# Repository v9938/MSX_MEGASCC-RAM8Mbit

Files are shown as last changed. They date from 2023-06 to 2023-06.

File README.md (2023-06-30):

# MSX MEGA-SCC RAM 8Mbit version  

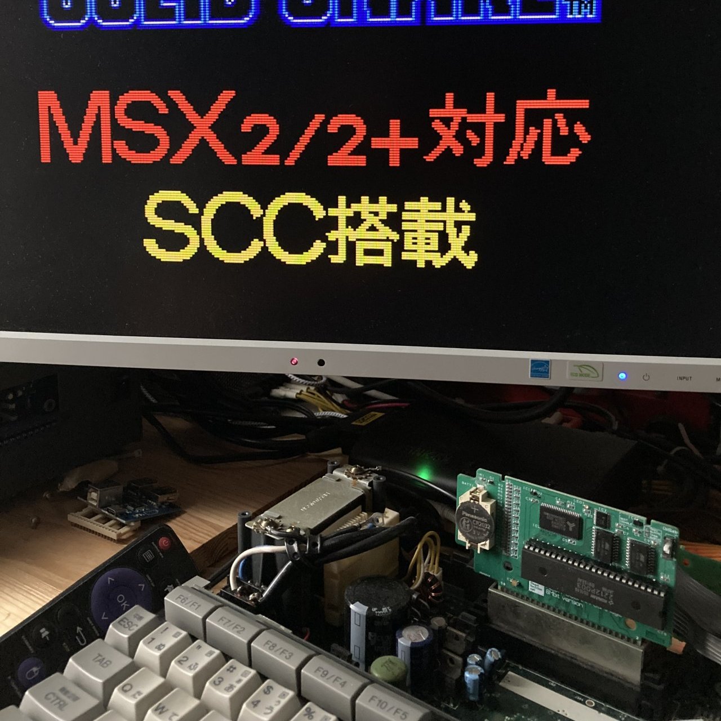
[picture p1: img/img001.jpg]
  

SCCのFlash Cartridge MEGA-SCC(似非SCC)のSRAM Versionです。  
SCC (2212P003) の最大容量は4Mbitですが、独自拡張をすることで8Mbitに対応しています。  

スイッチ切り替えにて4Mbitx2のマルチSCCカートとしても使用することができます。　　

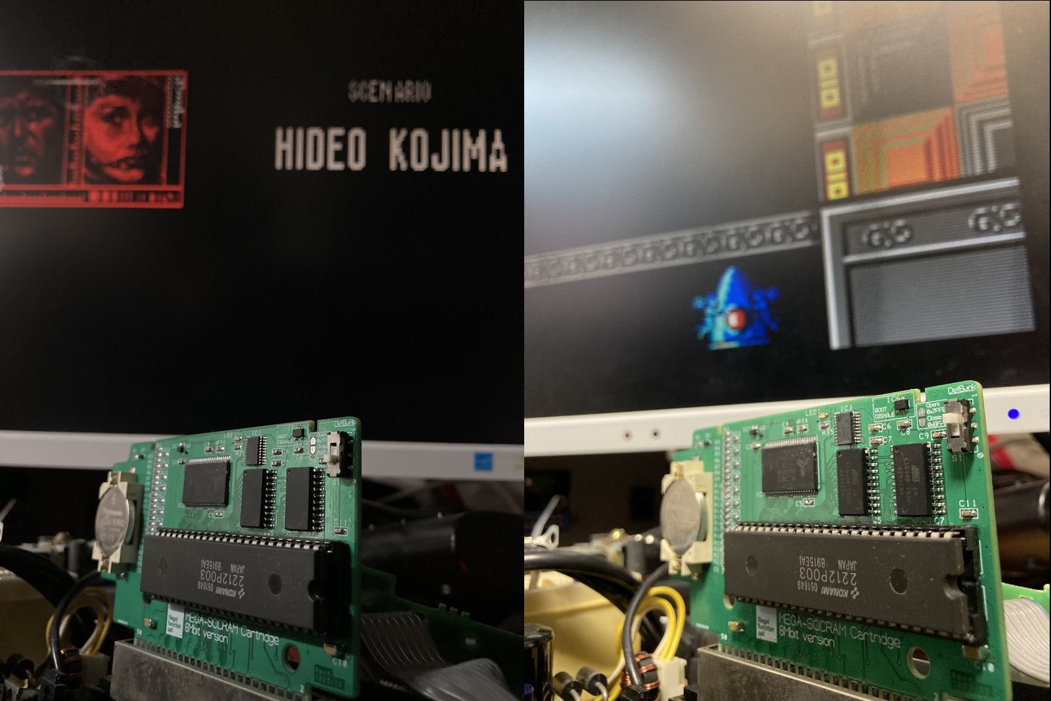
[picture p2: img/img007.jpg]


DACには、KONAMI051650と同等回路をあえて採用し、音質面で違いが出ないようにしています。   
ノイズ対策として大容量コンデンサーを搭載、SCC自体からでるノイズを低減させています。  

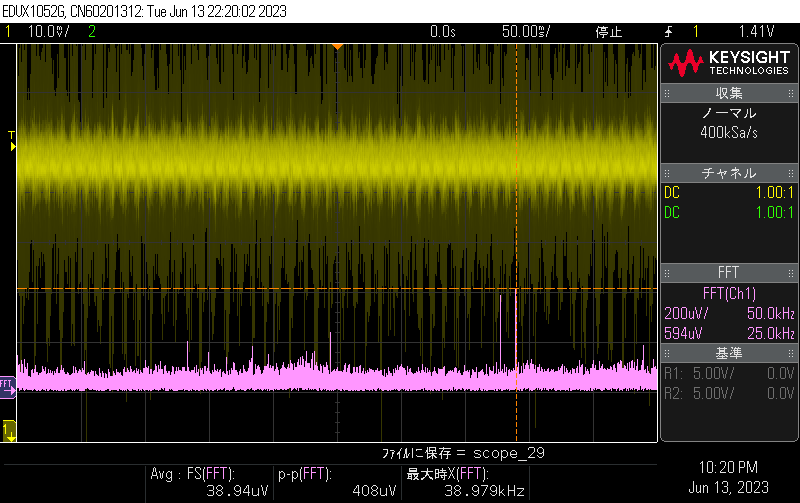
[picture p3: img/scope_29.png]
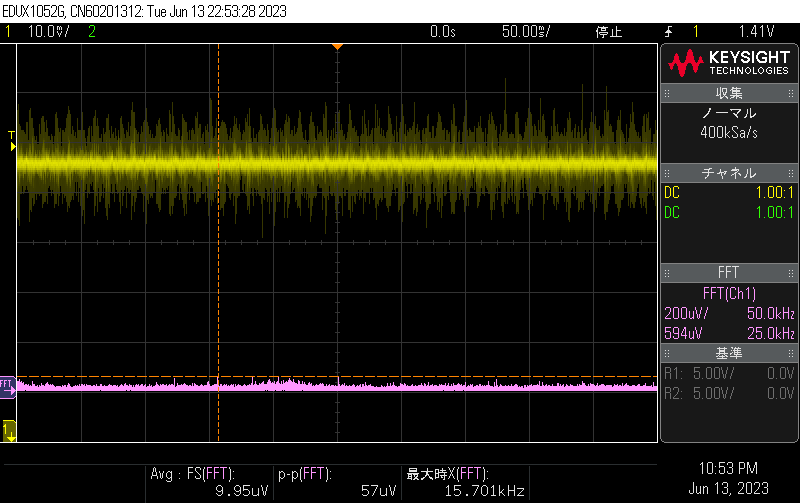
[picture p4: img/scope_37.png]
   
(左：オリジナル相当　右：本製品)

SRAMのバックアップ用には、電圧監視ICを搭載しておりデータ消失が起きにくい回路構成になっています。  

マグネットセンサーによる一時的な切り離し回路も実装しており、スマートなケース組み込みが可能です。  

## ■ 本製品の頒布について

下記ショップで取り扱っていただいています。  

家電のKENちゃん  
<https://www.kadenken.com/view/item/000000001604>  

ユーザにてSCC (2212P003) を実カートリッジから取り外しと本製品への半田付けが必要です。  
DACのKONAMI051650については取り外し不要です。基板上に等価回路を実装しています。  

カセットシェルは、KONAMIのMSX Cassette(要加工)   
またはRGR製のTransparent Cartridge Shell for MSX Konami-styleに対応しています。

## ■ 付属品
- MEGA-SCC RAM 基板(半完成品) x 1
- バックアップ電池 CR2032(パナソニック製) x 1  

## ■ 基板の説明

① 電池ボックス ... CR2032の電池ボックスです。  
② SCC取り付け場所 ... SCC (2212P003) を半田付けしてください。（ICソケットを使用するとケースに収まりません）  
③ マグネットセンサー... センサー近辺に磁石を近づけると、一時的にカセットを切り離すことができます。  
④ BANK切り替えスイッチ ... マルチSCCカートで使用時に使用するバンクを切り替えます。  
⑤ LED ... ソフト制御可能なLEDです。  

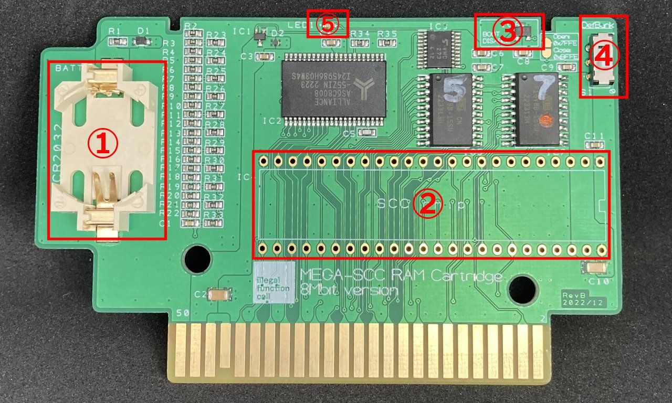
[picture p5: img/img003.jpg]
  

## ■ 基板の組み立て
本製品は、表面実装部品はすべて実装済みの半完成品での頒布になります。  

IC4に、SCC (2212P003) を半田付け、電池を取り付ければ完成です。取り付け方向に注意してください。  

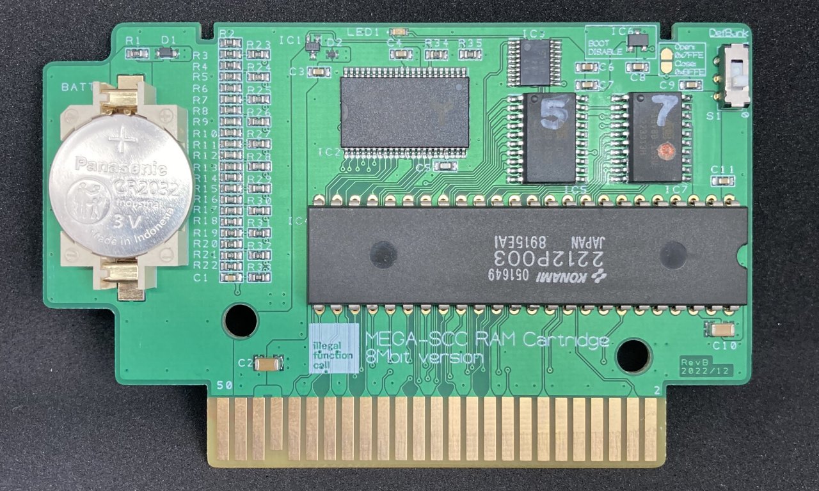
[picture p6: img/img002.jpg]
  

## ■ 電池の取り付け・交換方法
電池の＋側を上にして取り付けください。  
挿入時は、電池ケース凹部に＋側の表示側を先にはめ込んでください。  
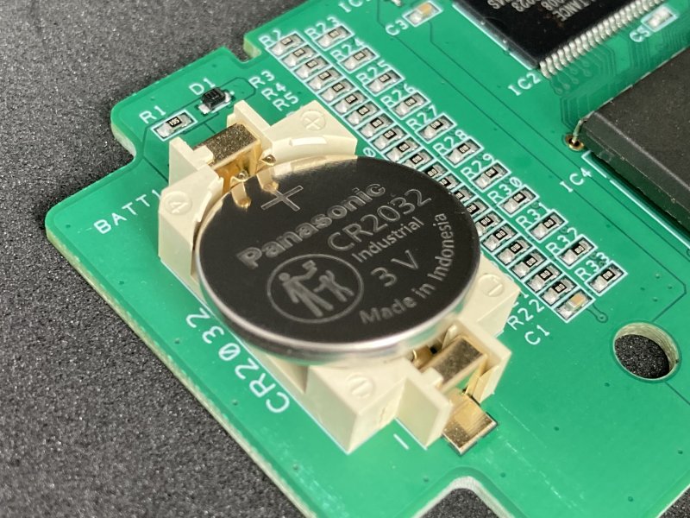
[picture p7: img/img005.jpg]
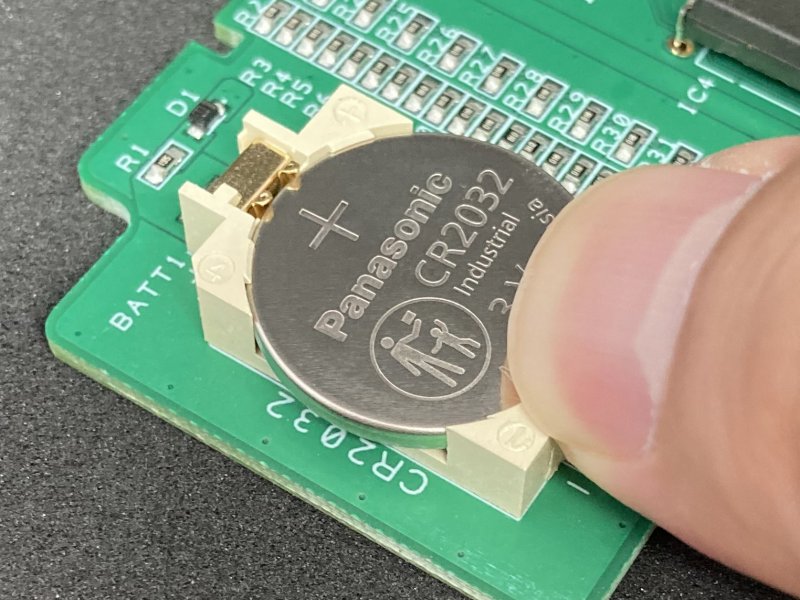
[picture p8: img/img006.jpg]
   

（許容充電電流のスペックにより）  
交換品のCR2032については、パナソニック/マクセル/SONY/村田製を推奨します。  

## ■ マグネットセンサーの使い方
センサー近辺に磁石を近づけると、一時的にカセットを切り離すことができます。  
SRAM書き換え時など、ROMから起動させたくない場合に利用してください。  
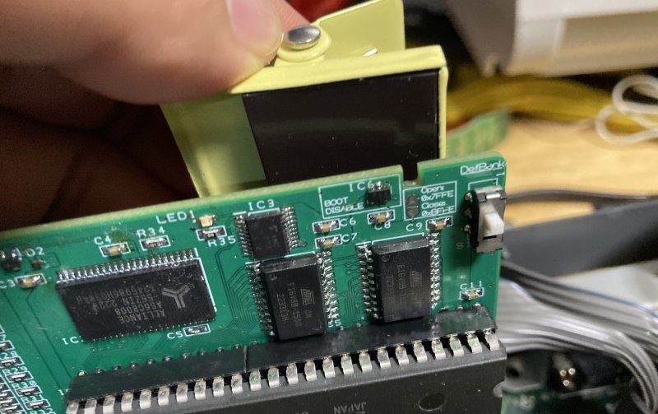
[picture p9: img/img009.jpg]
  

## ■ バンク切り替えスイッチ
スイッチの切り替えで前半と後半4MbitをSWAPすることができます。  
動作中はどちらかに固定して使用してください。  

4MbitまでのROMデータを使用する場合はマルチカートとして使用することが可能です。  
使いたいBANKにスイッチを切り替えて使用してください。  

## ■ KONAMI カセットシェルを使う場合の注意
シェルの加工が必要です。赤丸の突起を折り取ってください。  
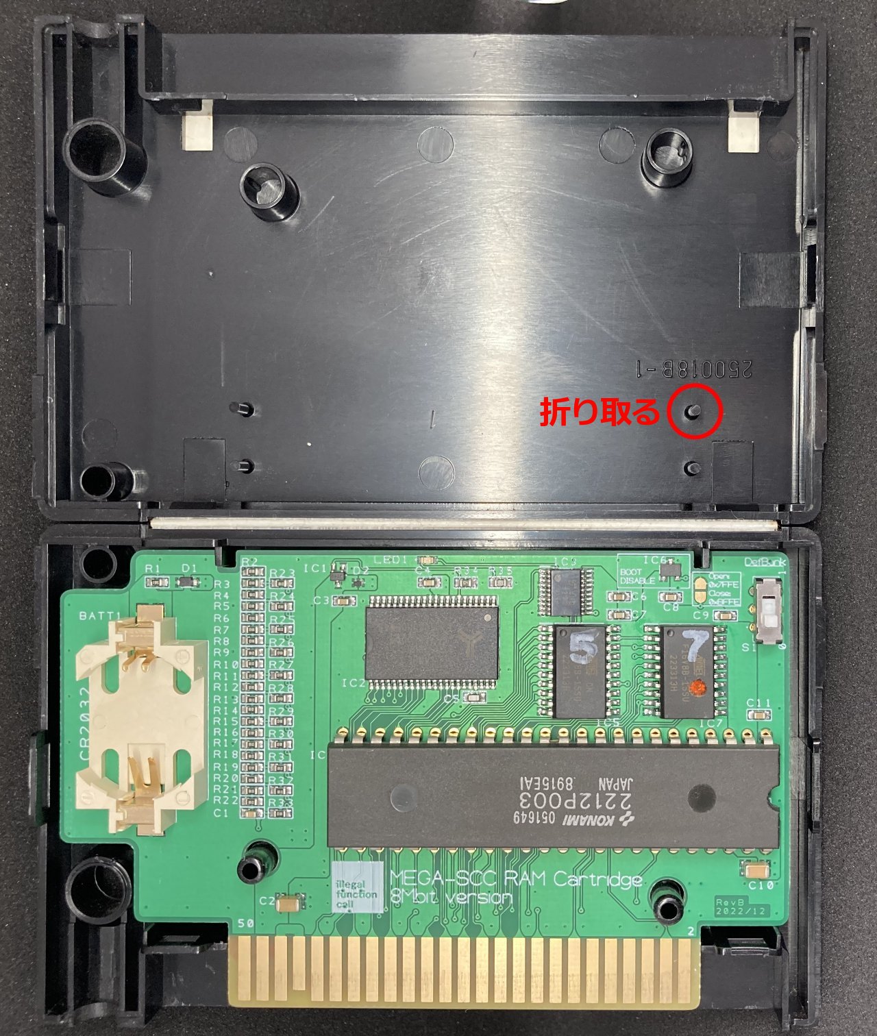
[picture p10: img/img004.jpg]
  

## ■ 動作確認ソフト
動作確認用に、SRAM領域をWrite/Read/Verifyする。SCCRAM_TESTを用意しています。
```
>sccram.com
```
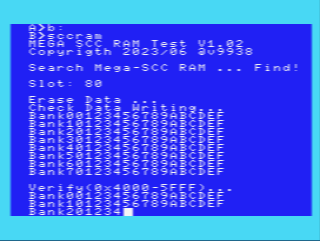
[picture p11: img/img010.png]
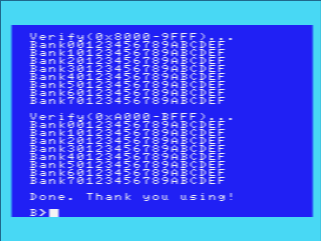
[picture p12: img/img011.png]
   

ソースコードは、z88dkでコンパイル可能です。コンパイルオプションは下記になります。  
```
>zcc +msx -create-app -subtype=msxdos -lmsxbios  main.c -o xxxx.com`  
```

## ■ その他対応ソフトについて
niga氏作成のMGLOADにて、拡張領域を含み、認識および書き込み可能なことを確認しています。  

### ●MGINST.COMについて
SCC RAM DISKの作成ができる辻川氏のMGINST.COMについては、  
似非SCC RAMと非互換部分の問題でフリーズします。  
同梱しているPatchを実行して修正してください。(似非SCC RAMより8K Byte使える容量が減ります)  

[MGINST.COM Ver2.15用Patchソフト](./MGINST_PATCH/mgpatch.com) [[zip形式]](./MGINST_PATCH/mgpatch.zip)  

実行手順：
1．MGINST.COMを実行して、RAMDISKを作成します。
```
>mginst DISKBIOS.ROM /Sxx /D
```
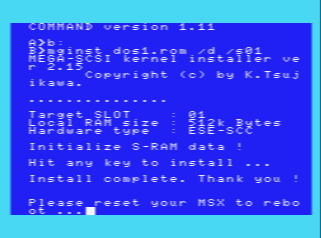
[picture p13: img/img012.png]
  

2. 指示に従い再起動しDOSを起動させます。  
　 起動できない場合は切り離しスイッチを使ってDISKからDOSを起動させてください。  

3. MGPATCH.COMを実行し、Patchを当てます。実行後は再起動してください。
```
>mgpatch
```
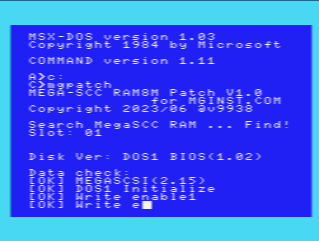
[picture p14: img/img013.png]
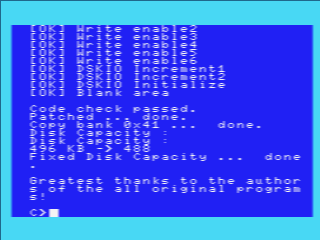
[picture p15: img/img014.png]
   

## ■SRAMのバックアップについて
電圧監視ICにて、本機の供給電圧が4V以下(<140ms)になった時にバックアップモードに移行します。  
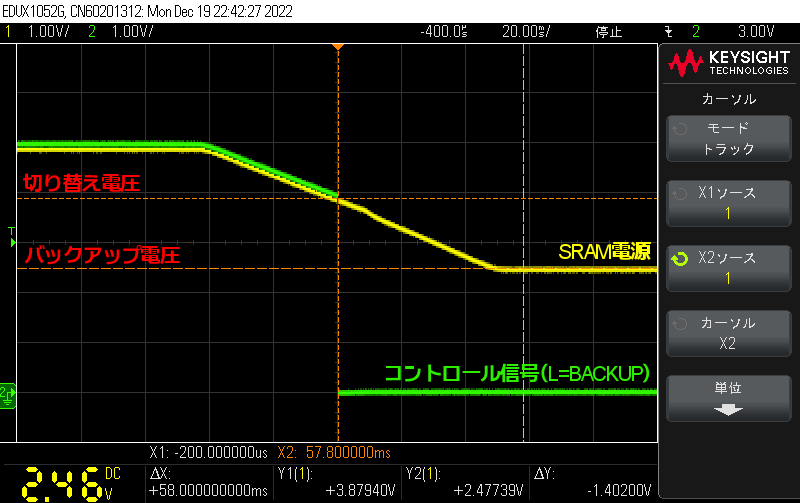
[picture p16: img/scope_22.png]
 　　

バックアップ電流は、7～6uA程度で、CR2023の公称容量220mAでは3～4年程度データ保存が可能です。  

## ■本機の仕様について

### ●メモリマップ
オリジナルのSCC ROMに準拠しています。

| Page (8kB) | Switching address | Initial segment |  
| --- | --- | --- |
| BANK1:4000h ~ 5FFFh  | 5000h (mirrors: 5001h ~ 57FFh) | 0 |  
| BANK2:6000h ~ 7FFFh  | 7000h (mirrors: 7001h ~ 77FFh) | 1 |  
| BANK3:8000h ~ 9FFFh  | 9000h (mirrors: 9001h ~ 97FFh) | 2 |  
| BANK4:A000h ~ BFFFh  | B000h (mirrors: B001h ~ B7FFh) | 3 |  

Segmentは、00～3fhが使用できます。  
| BIT7 | BIT6 | BIT5 | BIT4 | BIT3 | BIT2 | BIT1 | BIT0 |  
| ---- | ---- | ---- | ---- | ---- | ---- | ---- | ---- |
| Unused | Unused | Segment[5] | Segment[4] | Segment[3] | Segment[2] | Segment[1] | Segment[0] |  
  
Bit 0 ~ 5 = Segment number  
Bit 6 ~ 7 = Unused  

※BANK3 Segment 3fhは、SCCのWave Memoryに割り当てられている箇所があります。  

### ● コントロールレジスタ(7FFE-7FFFh)
書き込み専用のレジスタです。上位番地およびRAMへの書き込みをコントロールをするレジスタになります。  
アドレスは7FFE/7FFFhです。どちらのアドレスでも同じ扱いになります。  

| BIT7 | BIT6 | BIT5 | BIT4 | BIT3 | BIT2 | BIT1 | BIT0 |  
| ---- | ---- | ---- | ---- | ---- | ---- | ---- | ---- |
| LED | UPPER/LOWER | Unused | SRAM WRITE | Unused | Unused | Unused | Unused |  
  
Bit 4 = SRAM書き込みモード切替   
　　　　　0=SRAM書き込み禁止,BANK切替有効 / 1=書き込み可,BANK切替無効  

Bit 6 = SRAM上位番地/下位番地選択   
　　　　　0=SRAM前半4Mbit指定/1=SRAM後半4Mbit指定  
  
Bit 7 = LED  
　　　　　0=LED消灯/1=LED点灯  

## ■ 似非SCC RAMとの仕様の違いについて
512KByte以上の領域の扱いについて、似非SCC RAMと下記の仕様違いがあると思われます。  
（実物持っていないので、ちゃんと調べていません＾＾；）  

当該スロットのPAGE1上からSRAM UPPER/LOWERのコントロールレジスタ書き換えた場合は、  
本機では自身のデータが切り替わることに注意してください。  

| カセットの種類 | コントロ-ルレジスタ SRAM UPPER/LOWERのSRAM番地の切り替え |  
| ---- | ---- |
| 似非SCC RAM　| BANK3(8000～9FFFh)/BANK4(A000～BFFFh)のアドレス領域で有効 |  
| MEGA-SCCRAM | すべてのBANK1～BANK4(8000～BFFFh)で有効 |  

## ■ カートリッジ基板について

回路図、および基板のガーバデータを同梱しています。  
  
### ●基板
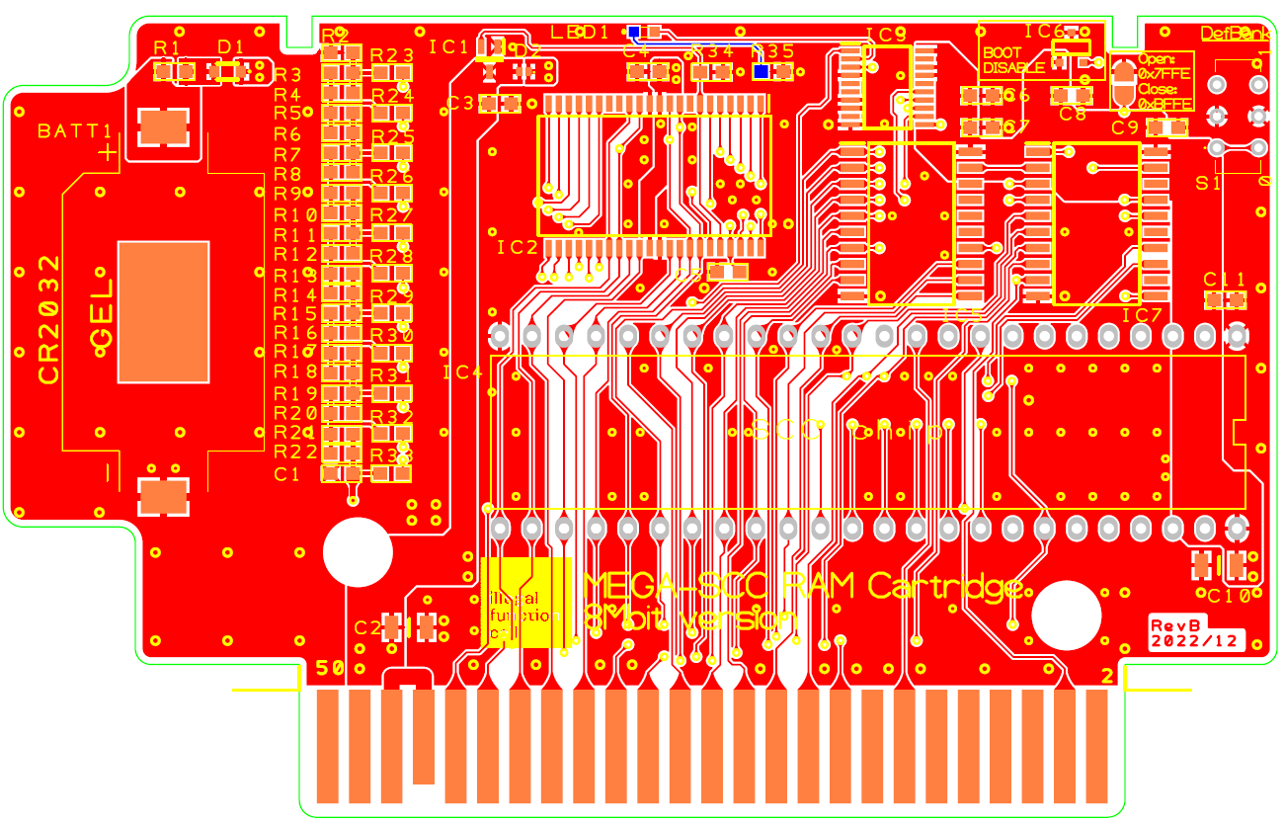
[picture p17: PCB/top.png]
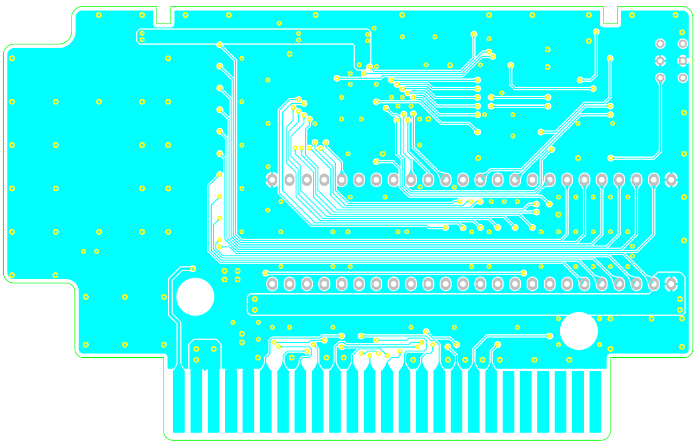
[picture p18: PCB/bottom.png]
  　  

### ●回路図

全体の回路図については下記を参照してください。
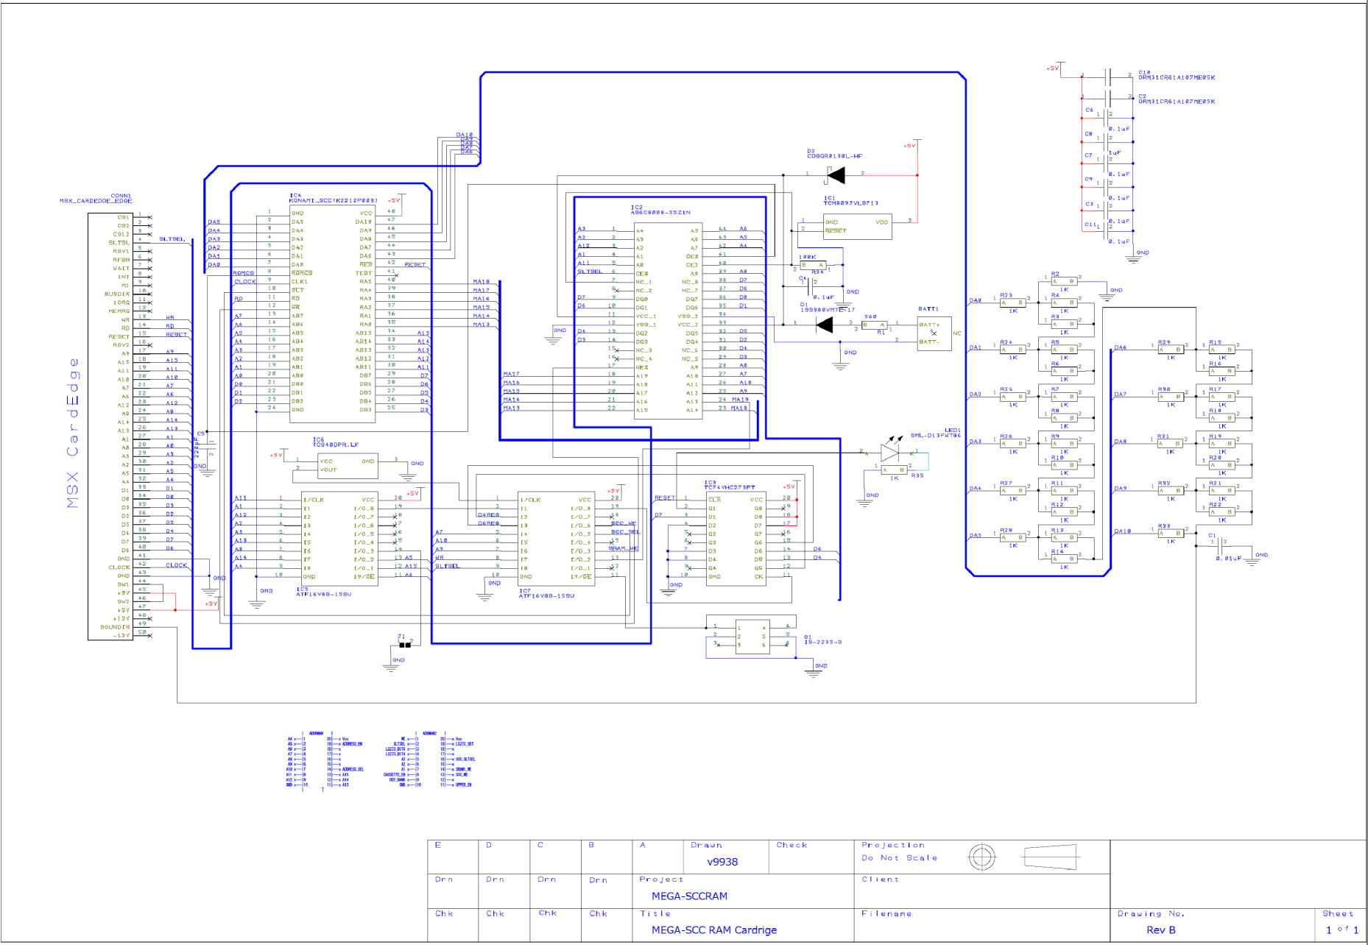
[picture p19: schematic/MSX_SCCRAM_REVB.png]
  

### ●部品表
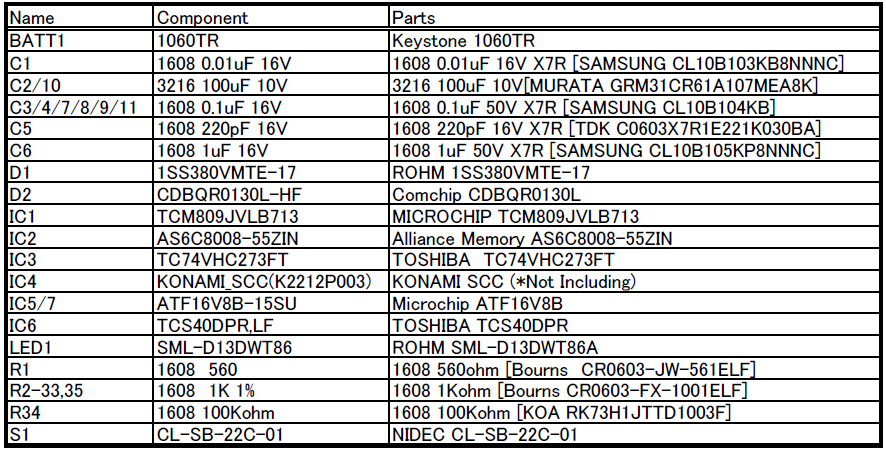
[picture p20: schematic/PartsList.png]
  

### ●CPLD
Microchip ATF16V8を使用しています。  
JEDファイルは下記になります。

[IC5 ADDRMAN](./CPLD/IC5_ADDMAN/ADDRMAN.jed)  
[IC7 ADDRMAN2](./CPLD/IC7_ADDMAN2/ADDMAN2.jed)

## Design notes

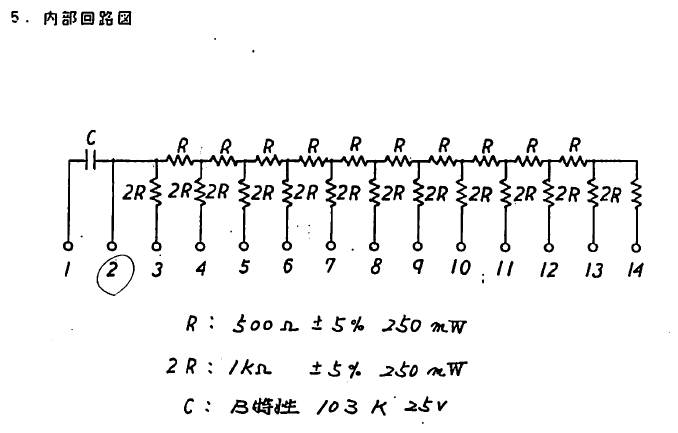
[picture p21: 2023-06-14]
schematic/KONAMI_DAC.png

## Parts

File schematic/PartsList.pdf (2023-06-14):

Name | Component | Parts
BATT1 | 1060TR | Keystone 1060TR
C1 | 1608 0.01uF 16V | 1608 0.01uF 16V X7R [SAMSUNG CL10B103KB8NNNC]
C2/10 | 3216 100uF 10V | 3216 100uF 10V[MURATA GRM31CR61A107MEA8K]
C3/4/7/8/9/11 | 1608 0.1uF 16V | 1608 0.1uF 50V X7R [SAMSUNG CL10B104KB]
C5 | 1608 220pF 16V | 1608 220pF 16V X7R [TDK C0603X7R1E221K030BA]
C6 | 1608 1uF 16V | 1608 1uF 50V X7R [SAMSUNG CL10B105KP8NNNC]
D1 | 1SS380VMTE-17 | ROHM 1SS380VMTE-17
D2 | CDBQR0130L-HF | Comchip CDBQR0130L
IC1 | TCM809JVLB713 | MICROCHIP TCM809JVLB713
IC2 | AS6C8008-55ZIN | Alliance Memory AS6C8008-55ZIN
IC3 | TC74VHC273FT | TOSHIBA TC74VHC273FT
IC4 | KONAMI_SCC(K2212P003) | KONAMI SCC (*Not Including)
IC5/7 | ATF16V8B-15SU | Microchip ATF16V8B
IC6 | TCS40DPR,LF | TOSHIBA TCS40DPR
LED1 | SML-D13DWT86 | ROHM SML-D13DWT86A
R1 | 1608 560 | 1608 560ohm [Bourns CR0603-JW-561ELF]
R2-33,35 | 1608 1K 1% | 1608 1Kohm [Bourns CR0603-FX-1001ELF]
R34 | 1608 100Kohm | 1608 100Kohm [KOA RK73H1JTTD1003F]
S1 | CL-SB-22C-01 | NIDEC CL-SB-22C-01

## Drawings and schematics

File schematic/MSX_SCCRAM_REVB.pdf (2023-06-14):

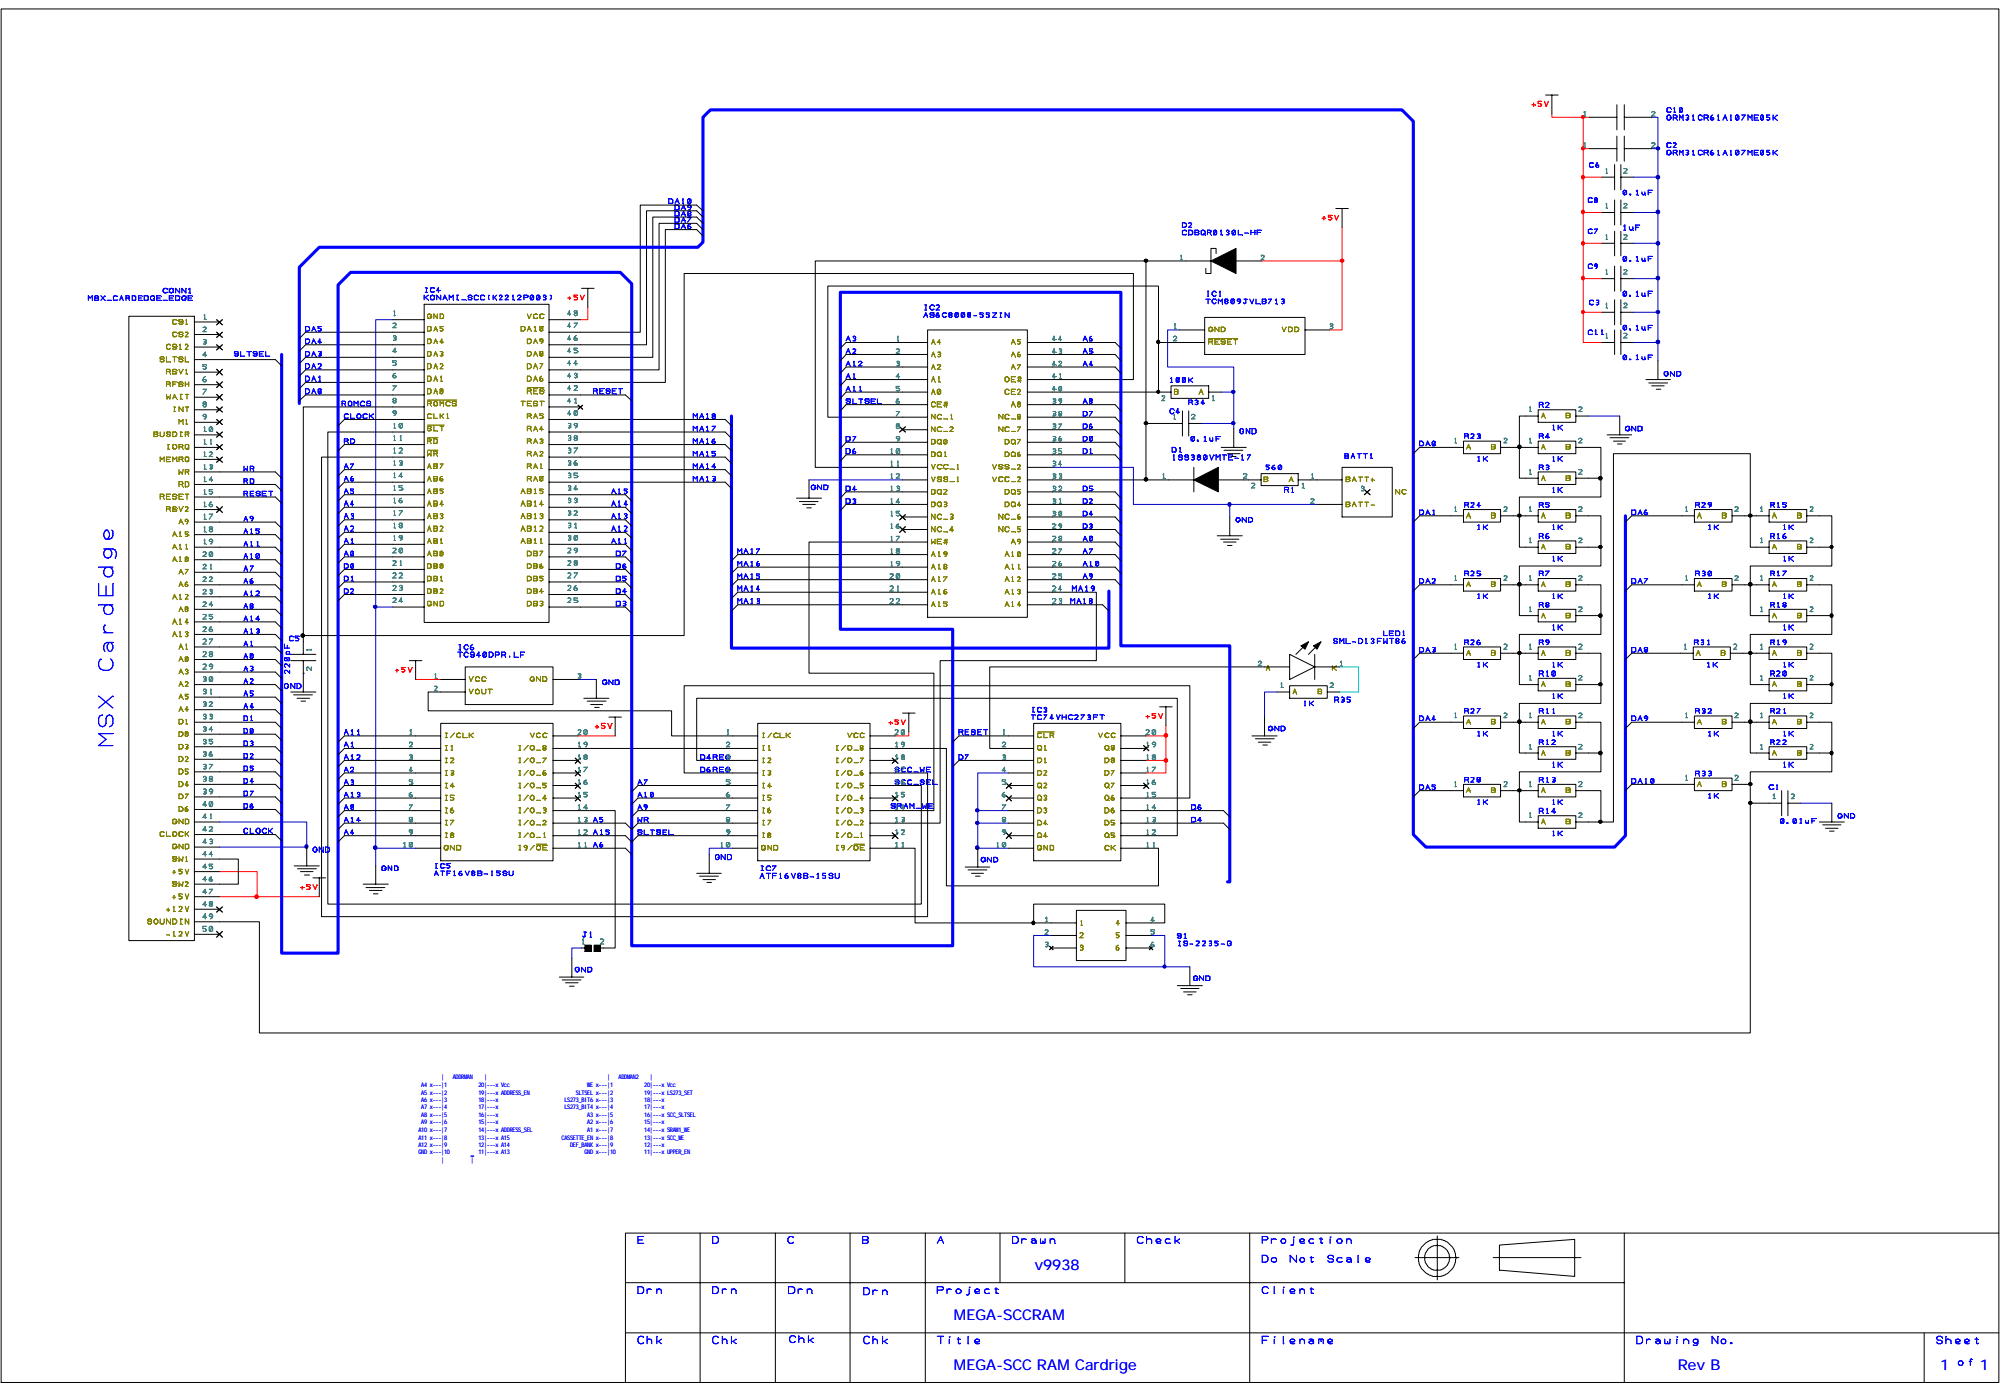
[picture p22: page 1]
MEGA-SCCRAM; MEGA-SCC RAM Cardrige; Rev B; ADDRMAN; 20|---x Vcc; 19|---x ADDRESS_EN; 14|---x ADDRESS_SEL; GND x---|10; ADDMAN2; SLTSEL x---|2; 19|---x LS273_SET; LS273_BIT6 x---|3; LS273_BIT4 x---|4; 16|---x SCC_SLTSEL; 14|---x SRAM1_WE; CASSETTE_EN x---|8; 13|---x SCC_WE; DEF_BANK x---|9; 11|---x UPPER_EN

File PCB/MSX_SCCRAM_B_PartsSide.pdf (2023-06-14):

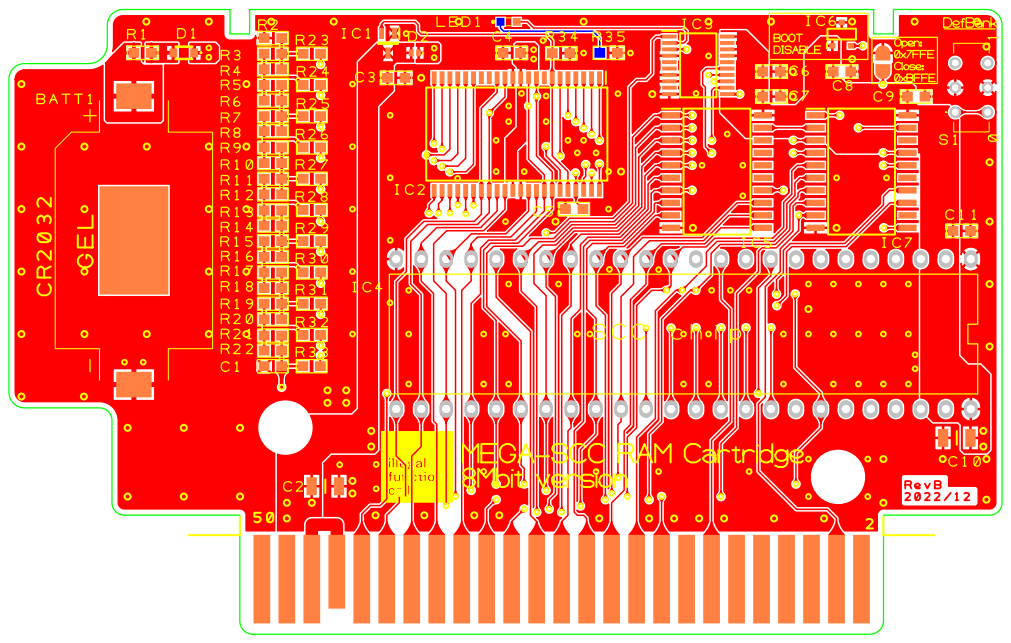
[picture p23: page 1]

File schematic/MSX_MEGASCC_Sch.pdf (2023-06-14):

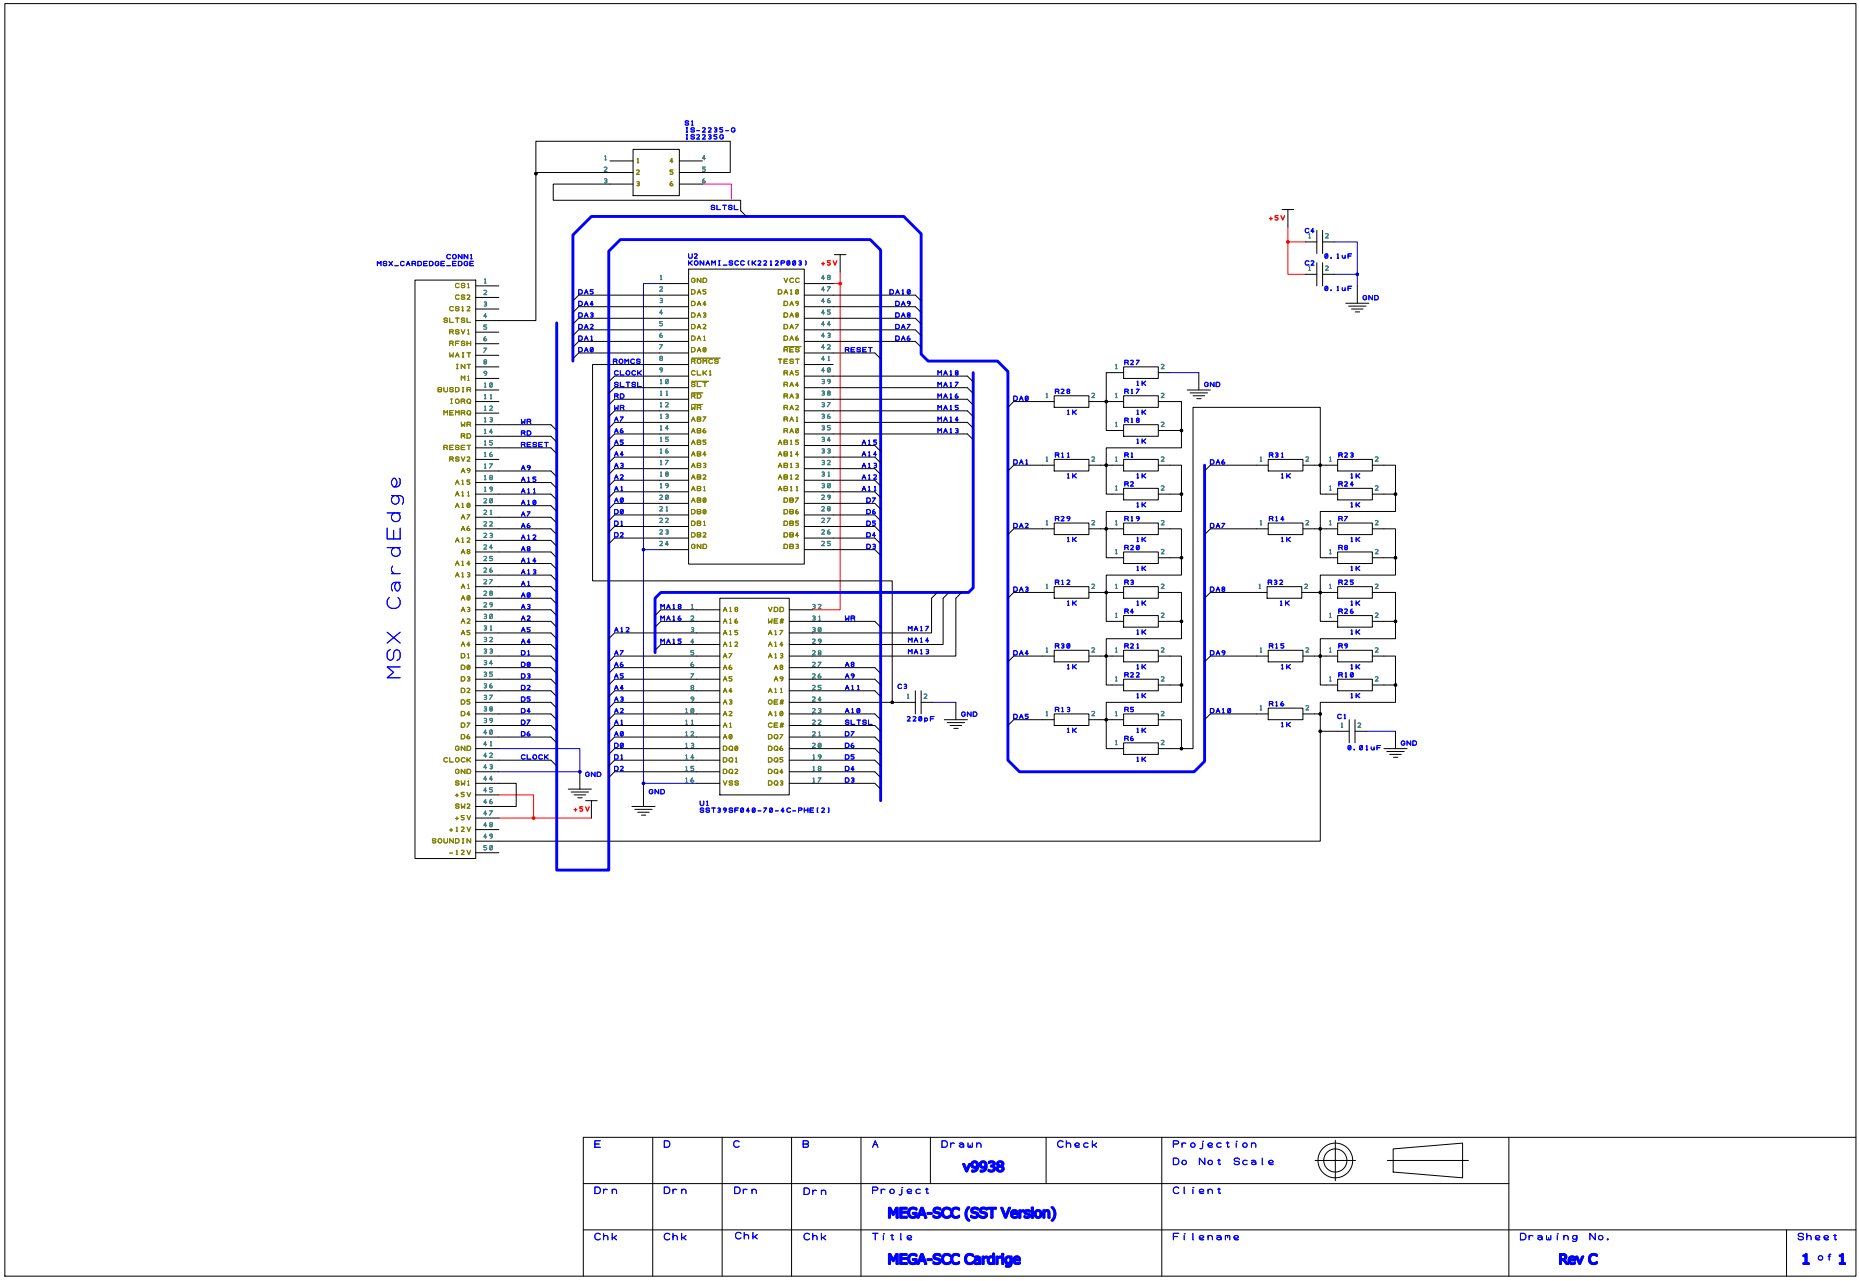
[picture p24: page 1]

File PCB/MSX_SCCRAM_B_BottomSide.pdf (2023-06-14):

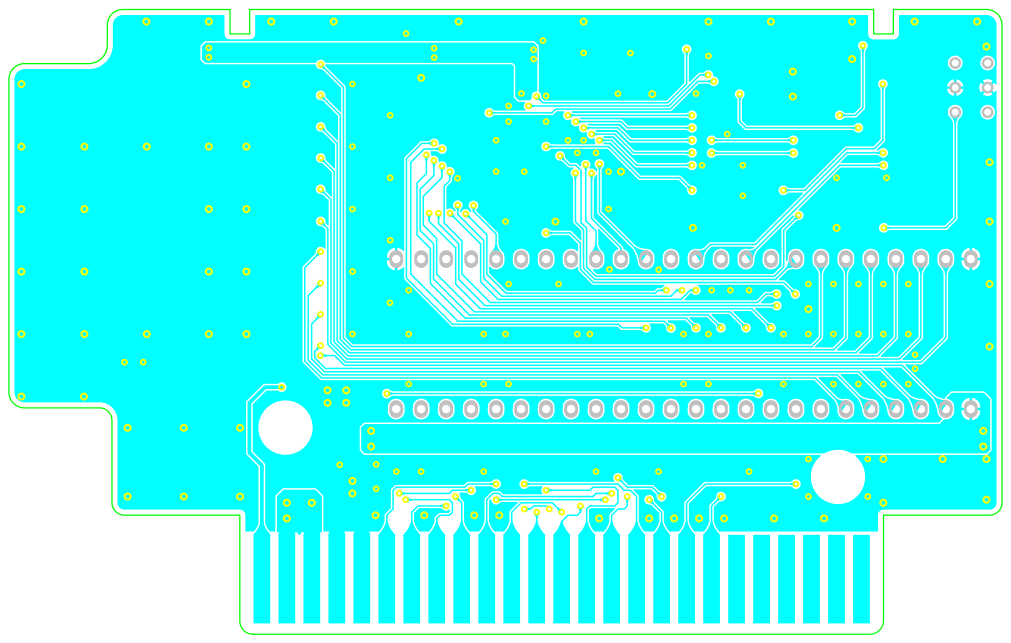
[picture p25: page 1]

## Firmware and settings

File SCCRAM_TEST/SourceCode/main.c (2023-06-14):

#include <stdio.h>
#include <msx.h>
#include <sys/ioctl.h>

#define VERSION "V1.02"
#define DATE "2023/06"

#define BUF_SIZE 128

//#include <msx/gfx.h>

unsigned char SelectSlot;		//Select Slot number
unsigned char eseBank;			//eseSCC 6000-7fffh Bank number
unsigned char *addressWrite;	//Write pointer
unsigned char eseSlot;			//eseSCC Slot number
unsigned char maxBank;			//ROM Size
unsigned char faildata;	

int findId;						//Flash ID


//Assembler SubRoutine
void asmCalls(){
#asm
chengePageSlot:
	di
    ld a,(_SelectSlot)	;Slot Number
    ld hl,04000h		;Select page 1
    call 0024h			;call ENASLT

    ld a,(_SelectSlot)	;Slot Number
    ld hl,08000h		;Select page 2
    call 0024h			;call ENASLT
	ret

restoreRAMPage:
RAMPass:
	ld a,000h				;
    ld (07ffeh),a			;Write enable

	ld a,(0f342h)		;Restore RAM Page (RAMAD1)
    ld hl,04000h		;Select page 1
    call 0024h			;call ENASLT

	ld a,(0f343h)		;Restore RAM Page (RAMAD2)
    ld hl,08000h		;Select page 2
    call 0024h			;call ENASLT
	ei
	ld hl,00000h		;find!
	ret
	
RAMErr:
	ld a,(0f342h)		;Restore RAM Page (RAMAD1)
    ld hl,04000h		;Select page 1
    call 0024h			;call ENASLT

	ld a,(0f343h)		;Restore RAM Page (RAMAD2)
    ld hl,08000h		;Select page 2
    call 0024h			;call ENASLT
	ei
	ld hl,0ffffh		;Not find!
	ret
	
checkSramData:
	push hl					;Backup Buffer address
	call chengePageSlot		;Page1 Select PAC Slot
	ld de,04000h			;PAC SRAM address
	ld bc,02000h			;Check Size
	pop hl					;Buffer address load
cmpLoop:
	ld a,(de)				;SRAM Data load
	cpi						;check data
	jr nz,RAMErr			;Compare Error->finsh
	jp po,RAMPass			;Compare Pass->finsh
	inc de					;SRAM Address++
	jr cmpLoop				;Continue Compare

#endasm
}

int writeEseSCC(unsigned char banknum)
{
#asm
	push hl					;Backup Buffer address
	call chengePageSlot		;4000-bfffh Change eseSCC Slot 
	pop hl
	ld a,l
	and 040h
	ld h,a
    ld (07ffeh),a			;upperbank sel

	ld a,l
	and 03fh
    ld (05000h),a			;Bank 4000-5fff

	ld a,l
	or a
	jr z,skipChkData
	ld a,(04000h)
	cp 05ah
	jp z,RAMErr
	
skipChkData:
	ld a,010h				;
	or h
    ld (07ffeh),a			;Write enable

	ld a,l
	ld d,a
	
	rrc a
	rrc a
	and 0c0h
	or l
	xor 05ah
	ld d,a
	ld hl,04000h			;RAM address
	ld bc,02000h			;Transfer Size
loopWr:
    ld (hl),d			;Write enable
	inc d
	inc hl
	dec bc
	ld a,b
	or c
	jr nz,loopWr
	
	jp restoreRAMPage
#endasm
}

void resetEseSCC(unsigned char banknum)
{
#asm
	push hl					;Backup Buffer address
	call chengePageSlot		;4000-bfffh Change eseSCC Slot 
	pop hl

	ld a,l
	and 040h
	ld h,a

	ld a,001h
	ld (07000h),a
	
	ld a,l
	and 03fh
    ld (05000h),a			;Bank 4000-5fff

	ld a,010h				;
	or h
    ld (07ffeh),a			;Write enable

	xor a
	ld (04000h),a
	jp restoreRAMPage
#endasm
}

int readEseSCC_B4000(unsigned char banknum)
{
#asm
	push hl					;Backup Buffer address
	call chengePageSlot		;4000-bfffh Change eseSCC Slot 
	pop hl
	ld a,l
	and 03fh
	ld (05000h),a			;Bank 4000-5fff
	ld de,04000h			;RAM address

readchk:
	ld a,l
	and 040h
    ld (07ffeh),a			;Write enable

	ld a,l
	rrc a
	rrc a
	and 0c0h
	or l
	xor 05ah
	ex de,hl
	ld d,a
	ld bc,02000h			;Transfer Size
loopB4:
	ld a,d
	cp (hl)
	jp nz,CompareErr
chkBack:
	inc d
	inc hl
	dec bc
	ld a,b
	or c
	jr nz,loopB4

	jp restoreRAMPage
CompareErr:
	ld a,b
	or b
	jr nz,CompErrTrue
	ld a,c
	cp 002h
	jr nz,CompErrTrue
	ld a,(HL)
	or a
	jr z,chkBack
CompErrTrue:
	push hl
	ld a,(0f342h)		;Restore RAM Page (RAMAD1)
    ld hl,04000h		;Select page 1
    call 0024h			;call ENASLT

	ld a,(0f343h)		;Restore RAM Page (RAMAD2)
    ld hl,08000h		;Select page 2
    call 0024h			;call ENASLT
	ei
	pop hl
	ld a,(hl)
	ld (_faildata),a
	ret
#endasm
}

int readEseSCC_B6000(unsigned char banknum)
{
#asm
	push hl					;Backup Buffer address
	call chengePageSlot		;4000-bfffh Change eseSCC Slot 
	pop hl
	ld a,l
	and 03fh
    ld (07000h),a			;Bank 4000-5fff
	ld de,06000h			;RAM address
	jr readchk
#endasm
}

int readEseSCC_B8000(unsigned char banknum)
{
#asm
	push hl					;Backup Buffer address
	call chengePageSlot		;4000-bfffh Change eseSCC Slot 
	pop hl
	ld a,l
	and 03fh
    ld (09000h),a			;Bank 4000-5fff
	ld de,08000h			;RAM address
	jr readchk
#endasm
}

int readEseSCC_BA000(unsigned char banknum)
{
#asm
	push hl					;Backup Buffer address
	call chengePageSlot		;4000-bfffh Change eseSCC Slot 
	pop hl
	ld a,l
	and 03fh
    ld (0B000h),a			;Bank 4000-5fff
	ld de,0A000h			;RAM address
	jp readchk
#endasm
}

int readEseSCC_B9800(unsigned char banknum)
{
#asm
	push hl					;Backup Buffer address
	call chengePageSlot		;4000-bfffh Change eseSCC Slot 
	pop hl
	ld a,l
	and 03fh
	ld (09000h),a			;Bank 4000-5fff
	ld de,04000h			;RAM address

	ld a,l
	and 040h
    ld (07ffeh),a			;Write enable

	ld a,l
	rrc a
	rrc a
	and 0c0h
	or l
	xor 05ah
	ex de,hl
	push af
	ld bc,02000h			;Transfer Size
	ld de,09800h 
loopB98:
	or a
	sbc hl,de
	ex af,af'
	add hl,de
	ex af,af'
	jr z,SkipSCCWork
SkipEnd:
	pop af
	cp (hl)
	jp nz,CompareErr
	inc a
	push af
	inc hl
	dec bc
	ld a,b
	or c
	jr nz,loopB98

	pop af
	jp restoreRAMPage

SkipSCCWork:
	ld de,09900h 
dummyLoop:
	inc a
	inc hl
	dec bc
	or a
	sbc hl,de
	ex af,af'
	add hl,de
	ex af,af'
	jr nz,dummyLoop
	push af
	jr SkipEnd

#endasm
}

int chkEseSCC() __z88dk_fastcall __naked {
#asm
	di
	di
    ld a,(_SelectSlot)	;Slot Number
    ld hl,04000h		;Select page 1
    call 0024h			;call ENASLT

    ld a,(_SelectSlot)	;Slot Number
    ld hl,08000h		;Select page 2
    call 0024h			;call ENASLT

	ld hl,07ffeh
	ld a,(hl)			; backup data
	ld b,a			
	or a
	jr z,data_zero
	ld c,000h			; SCC RAM Write disable
	ld (hl),c			;
    ld a,(hl)			; load data
	or a
	jr nz,CheckData

	ld c,001h			; SCC RAM Write disable
	ld (hl),c			;
    ld a,(hl)			; load data
	xor 001h
	jr nz,CheckData

    ld (hl),b			; Restore Data
	jp RAMErr

data_zero:
	ld c,000h			; SCC RAM Write disable
    ld (hl),c			;

CheckData:
	ld hl,04000h		;Check Address 
	call chkData		;Check 4000h
	jp z,RAMErr			;Fail (RAM Slot?)

	ld hl,06000h		;Check Address 
	call chkData		;Check 6000h
	jp z,RAMErr			;Fail (RAM Slot?)
	
	ld a,010h				;
    ld (07ffeh),a			;Write enable

	ld hl,04000h		;Check Address 
	call chkData		;Check 4000h
	jp nz,RAMErr			;Fail (RAM Slot?)
	inc hl				;One more check...
	call chkData		;Check 4001h
	jp nz,RAMErr		;Fail (Not Use/ROM Slot?)

	ld hl,06000h		;Check Address 
	call chkData		;Check 6000h
	jp nz,RAMErr			;Fail (RAM Slot?)
	inc hl				;One more check...
	call chkData		;Check 4001h
	jp nz,RAMErr		;Fail (Not Use/ROM Slot?)
	jp RAMPass

chkData:
	ld a,(hl)			;Read SRAM Data
	ld b,a				;Backup org data
	xor 0ffh			;Data bitflip
	ld (hl),a			;Write SRAM Data
	ld c,(hl)			;Read SRAM Data (Again)
	ld (hl),b			;pop ori Data
	xor c				;2nd Data(XOR)?
	ret					;z = Read/Write PASS 
#endasm
}

void findEseSCC(void){
	unsigned char i;
	unsigned int chipId;
	
	if ((SelectSlot & 0xf0) == 0x80){
		//Expantion Slot Check
		for (i=0;i<4;i++){
			if (chkEseSCC() == 0x0000) {
				eseSlot = SelectSlot;
			}
			SelectSlot = SelectSlot + 4;
		}
	}else{
		//Master Slot Check
		chipId = chkEseSCC();
		if (chkEseSCC() == 0x0000) {
			eseSlot = SelectSlot;
		}
	}
}
	
int main(int argc,char *argv[])
{

	int i;
	unsigned char dat;
	int add;
	
	
	printf("MEGA SCC RAM Test %s\n",VERSION);
	printf("Copyrigth %s @v9938\n\n",DATE);

	if (argc<1){
		printf( "sccram\n");
		printf( "This program will write the selected file to the flash ROM.\n");
		return 0;
	}

	printf("Search Mega-SCC RAM ... ");
	eseSlot = 0;
	//Slot 1 Search
	SelectSlot = *((unsigned char *)0xfcc2) | 0x01;		//EXPTBL (SLOT1)
	findEseSCC();
	//Slot 2 Search
	SelectSlot = *((unsigned char *)0xfcc3) | 0x02;		//EXPTBL (SLOT2)
	findEseSCC();
	//Slot 3 Search
	SelectSlot = *((unsigned char *)0xfcc4) | 0x03;		//EXPTBL (SLOT3)
	findEseSCC();

	if (eseSlot == 0) {								// Not find eseSCC
		printf("NOT find\n");
		printf("Bye...\n");
		return -1;
	}else{
		printf("Find!\n");
		printf("Slot: %02x",eseSlot);
	}

	//Bank set
	SelectSlot = eseSlot;
	eseBank = 0;
	printf("\n\nErase Data ...");
	for (dat=0;dat<0x80;dat++){
		resetEseSCC(dat);
	}
	printf("\nCheck Data Writing...");
	for (dat=0;dat<0x80;dat++){
		if (writeEseSCC(dat)!=0) break;
		if (dat%16 == 0) printf("\nBank%X",(dat>>4));
		printf("%X",0x0f & dat);
	}
	maxBank = dat;

	printf("\n\nVerify(0x4000-5FFF)...");
	for (dat=0;dat<0x80;dat++){
		add = readEseSCC_B4000(dat);
		if (add!=0) {
			printf("\nFail!(BANK%02x:0x%04x %02x)\n",dat,add,faildata);
			return -1;
		}
		if (dat%16 == 0) printf("\nBank%X",(dat>>4));
		printf("%X",0x0f & dat);
	}

	printf("\n\nVerify(0x6000-7FFF)...");
	for (dat=0;dat<0x80;dat++){
		add = readEseSCC_B6000(dat);

		if (add!=0) {
			printf("\nFail!(BANK%02x:0x%04x %02x)\n",dat,add,faildata);
			return -1;
		}
		if (dat%16 == 0) printf("\nBank%X",(dat>>4));
		printf("%X",0x0f & dat);
	}

	printf("\n\nVerify(0x8000-9FFF)...");
	for (dat=0;dat<0x80;dat++){
		if ((dat == 0x3f)||(dat == 0x7f)) {
			add = readEseSCC_B9800(dat);
		}else{
			add = readEseSCC_B8000(dat);
		}
		if (add!=0) {
			printf("\nFail!(BANK%02x:0x%04x %02x)\n",dat,add,faildata);
			return -1;
		}
		if (dat%16 == 0) printf("\nBank%X",(dat>>4));
		printf("%X",0x0f & dat);
	}

	printf("\n\nVerify(0xA000-BFFF)...");
	for (dat=0;dat<0x80;dat++){
		add = readEseSCC_BA000(dat);
		if (add!=0) {
			printf("\nFail!(BANK%02x:0x%04x %02x)\n",dat,add,faildata);
			return -1;
		}
		if (dat%16 == 0) printf("\nBank%X",(dat>>4));
		printf("%X",0x0f & dat);
	}

	printf("\n\nDone. Thank you using!\n");
	return 0;

}

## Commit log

2023-06-14 1st Release Version
    Release初版
    [MSX_SCCRAM_B - Bottom Copper (Resist).gbr, MSX_SCCRAM_B - Bottom Copper.gbr, MSX_SCCRAM_B - Drill Ident Drawing - [Through Hole].gbr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]
2023-06-14 Update README.md
    リンクミスを修正
2023-06-25 Update README.md
    MGINSTの注意事項を追記しました。
2023-06-30 Add RAMDISK patch 'mgpatch.com'
    mginstで作成したRAMディスクを動作させる為のパッチソフトを追加しました。
